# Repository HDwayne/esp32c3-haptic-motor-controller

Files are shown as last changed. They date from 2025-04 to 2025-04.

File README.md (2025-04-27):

# ESP32-C3 Haptic Motor Controller



The **ESP32-C3 Haptic Motor Controller** is a standalone board designed to drive multiple haptic motors, based on the ESP32-C3-MINI-1U module.  
It features a **DRV2605L** haptic driver for each motor. The board is powered by two parallel LiPo batteries.

> ⚠️ Warning: This project has not been tested and will not be tested. It is a concept prototype developed for a student project only. Use it at your own risk.

The PCB is a 4-layer board following the **JLC04161H-3313** stackup:
- **Outer layers**: signals.
- **Inner layers**: ground (GND) and 3.3 V power.

📏 Board dimensions: **80 mm x 35 mm**.

Here is a 3D model preview of the PCB layout:
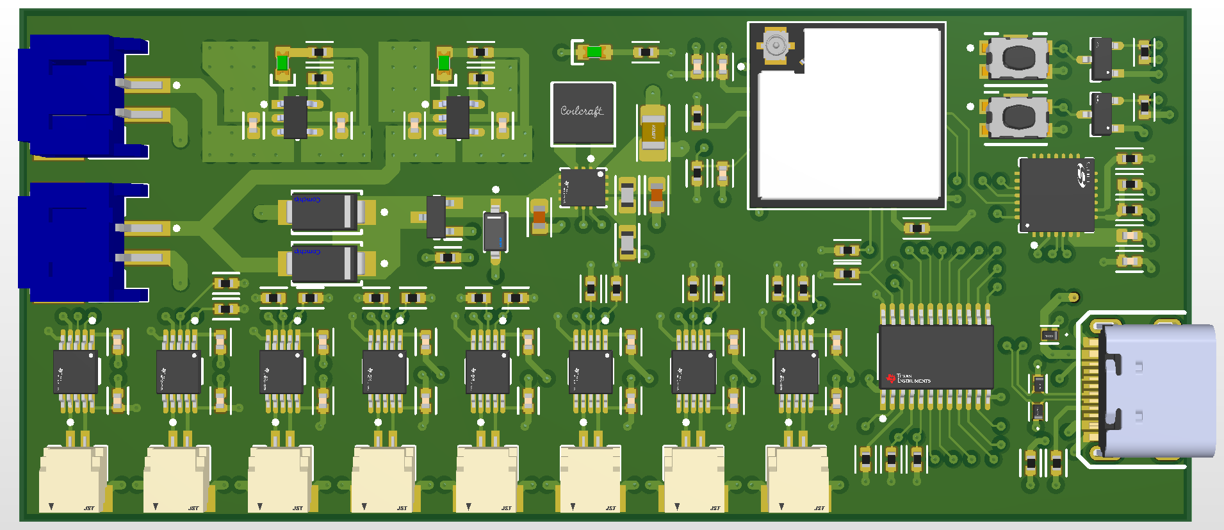
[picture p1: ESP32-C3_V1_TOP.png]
PCB 3D View BOTTOM

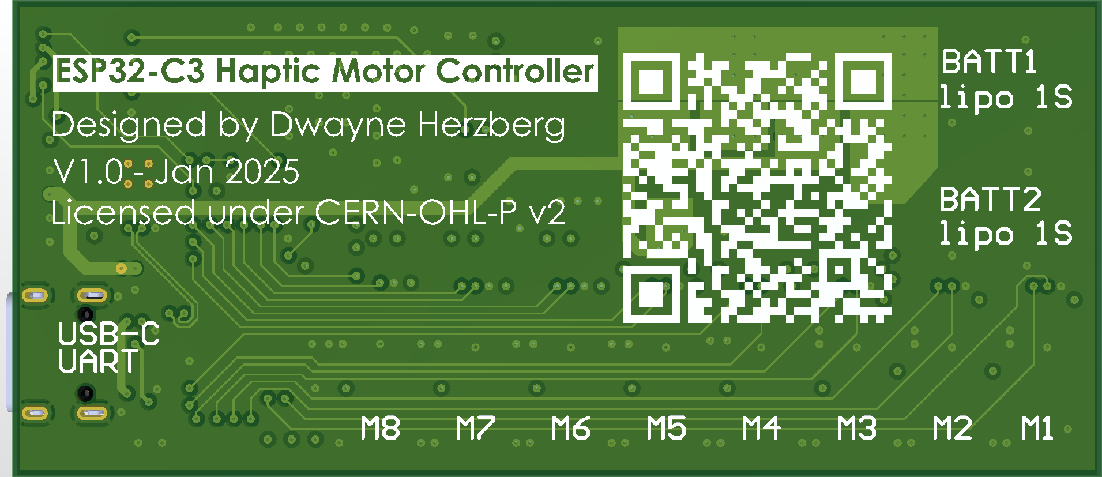
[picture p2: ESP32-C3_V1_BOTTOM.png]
PCB 3D View TOP


## Overview

- **ESP32-C3-MINI-1U** with Wi-Fi and Bluetooth LE
- **DRV2605L Haptic Drivers** (one per motor)
- **I²C Multiplexer TCA9548A**
- **Autonomous power** with two parallel LiPo batteries
- **TPS630250 Buck-Boost Converter** for stable 3.3 V
- **Simplified USB-C connector** for programming and charging
- **Independent battery chargers** for each battery
- **control buttons** (reset and boot)

## Project Contents

- **Altium Source Files** – Schematic and PCB Layout
- **Symbol & Footprint Libraries** – Custom libraries
- **Manufacturing Files** – Gerber files for PCB production
- **Assembly Files** – BOM and Pick & Place files

## License

This project is licensed under the [CERN Open Hardware Licence Version 2 – Permissive (CERN-OHL-P v2)](https://cern-ohl.web.cern.ch/).

See the `LICENSE.txt` file for full details.

---

**Dwayne Herzberg**  
Email: [dwayneherzberg@gmail.com](mailto:dwayneherzberg@gmail.com)

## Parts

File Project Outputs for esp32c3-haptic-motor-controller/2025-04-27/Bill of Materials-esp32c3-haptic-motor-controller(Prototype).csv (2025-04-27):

Comment | Description | Designator | Footprint | LibRef | Quantity | JLCPCB Part | Manufacturer | Manufacturer Part Number | Supplier | Supplier Part Number
1uF 35V | CAP CER 1UF 35V X5R 0402 | C1, C9, C10, C11, C12, C13, C14, C15, C16, C21, C22, C23, C24, C25, C26, C27, C28 | CAP_0402 | CL05A105KL5NRNC | 17 | C307413 | Samsung | CL05A105KL5NRNC | Digikey | 1276-6796-1-ND
0.1uF 50V | CAP CER 0.1UF 50V X7R 0402 | C2, C5 | CAP_0402 | CL05B104KB54PNC | 2 | C307331 | Samsung | CL05B104KB54PNC | Digikey | 1276-CL05B104KB54PNCCT-ND
10uF 10V | CAP CER 10UF 10V X5R 0402 | C3 | CAP_0402 | CL05A106MP8NUB8 | 1 | C307415 | Samsung | CL05A106MP8NUB8 | Digikey | 1276-6830-1-ND
4.7uF 16V | CAP CER 4.7UF 16V X5R 0402 | C4, C17, C18, C19, C20 | CAP_0402 | CL05A475MO5NUNC | 5 | C318563 | Samsung | CL05A475MO5NUNC | Digikey | 1276-6836-1-ND
10uF 10V | CAP CER 10UF 10V X5R 0603 | C6 | CAP_0603 | CL10A106KP8NNNC | 1 | C19702 | Samsung | CL10A106KP8NNNC | Digikey | 1276-1192-1-ND
10uF 6.3V | CAP CER 10UF 6.3V X5R 0603 | C7 | CAP_0603 | GRM188R60J106ME47D | 1 | C77041 | Murata | GRM188R60J106ME47D | Digikey | 490-3896-1-ND
47uF 6.3V | CAP CER 47UF 6.3V X5R 0805 | C8 | CAP_0805 | CL21A476MQYNNNE | 1 | C16780 | Samsung | CL21A476MQYNNNE | Digikey | 1276-1852-1-ND
AQ3045-01ETG | TVS DIODE 5.3VWM 12VC SOD882 | D2, D3, D4 | SP353001ETG | AQ3045-01ETG | 3 | C3710326 | Littelfuse | AQ3045-01ETG | Digikey | F9321CT-ND
GREEN | LED GREEN CLEAR 0603 SMD | D5, D8, D9 | LED_0603_GREEN | 150060GS75000 | 3 | C5252984 | Wurth Electronics | 150060GS75000 | Digikey | 732-4971-1-ND
40V 2A | DIODE SCHOTTKY 40V 2A DO214AC | D6, D7 | FP-DO-214AC-MFG | CDBA240LL-HF | 2 | C2886093 | Comchip | CDBA240LL-HF | Digikey | 641-1698-1-ND
40V 1A | DIODE SCHOTTKY 40V 1A SOD123 | D10 | FP-SOD123-IPC_B | 1N5819HW-7-F | 1 | C82544 | Diodes | 1N5819HW-7-F | Rs | 7082197P
TYPE-C-31-M-12 | USB Type C Connector Horizontal SMT | J1 | TYPE-C-31-M-12 | TYPE-C-31-M-12 | 1 | C165948 | Koren Hroparts | TYPE-C-31-M-12
S2B-PH-SM4-TB(LF)(SN) | Male Header, Pitch 2 mm, 1 x 2 Position, Height 5.5 mm, -25 to 85 degC, RoHS, Tape and Reel | J2, J7 | JST- S2B-PH-SM4-TB(LF)(SN)-2_V | CMP-1755-00001-1 | 2 | C295747
SM02B-SRSS-TB(LF)(SN) | CONN HEADER SMD R/A 2POS 1MM | J3, J4, J5, J6, J8, J9, J10, J11 | FP-SM02B-SRSS-TB_LF_SN-MFG | SM02B-SRSS-TB(LF)(SN) | 8 | C160402 | JST | SM02B-SRSS-TB(LF)(SN) | Future Electronics | 1161645
1uH | FIXED IND 1UH 9.6A 14.6MOHM SM | L1 | FP-XAL4020-102MEC-MFG | XAL4020-102MEC | 1 | C4555951 | Coilcraft | XAL4020-102MEC | Mouser | 994-XAL4020-102MEC
SS8050-G | TRANS NPN 25V 1.5A SOT-23-3 | Q1, Q2 | FP-SS8050-G-IPC_B | SS8050-G | 2 | C3199946 | Comchip | SS8050-G | Digikey | 641-1790-1-ND
DMP2045U-7 | MOSFET P-CH 20V 4.3A SOT23 | Q3 | SOT96P240X115-3N | DMP2045U-7 | 1 | C459541 | Diodes | DMP2045U-7 | Rs | 1827098P
10K | RES SMD 10K OHM 1% 1/16W 0402 | R1, R7, R8, R9, R10, R11, R12, R13, R14, R15, R16, R17, R18, R19, R20, R21, R22, R23, R24, R25, R26, R27, R28, R29 | RES_0402 | AC0402FR-0710KL | 24 | C144807 | Yageo | AC0402FR-0710KL | Digikey | YAG3436CT-ND
1K | RES 1K OHM 5% 1/16W 0402 | R2, R30, R33, R35 | RES_0402 | RC0402JR-071KL | 4 | C105637 | Yageo | RC0402JR-071KL | Digikey | 311-1.0KJRCT-ND
22K1 | RES 22.1K OHM 1% 1/16W 0402 | R3 | RES_0402 | RC0402FR-0722K1L | 1 | C163478 | Yageo | RC0402FR-0722K1L | Rs | 1987704
47K5 | RES 47.5K OHM 1% 1/16W 0402 | R4 | RES_0402 | RC0402FR-0747K5L | 1 | C137974 | Yageo | RC0402FR-0747K5L | Rs | 1987797
5K1 | RES SMD 5.1K OHM 1% 1/16W 0402 | R5, R6 | RES_0402 | AC0402FR-075K1L | 2 | C144745 | Yageo | AC0402FR-075K1L | Digikey | YAG3503CT-ND
562K | RES SMD 562K OHM 1% 1/10W 0603 | R31 | RES_0603 | AC0603FR-07562KL | 1 | C227963 | Yageo | AC0603FR-07562KL | Digikey | 13-AC0603FR-07562KLCT-ND
180K | RES 180K OHM 1% 1/10W 0603 | R32 | RES_0603 | RC0603FR-07180KL | 1 | C123419 | Yageo | RC0603FR-07180KL | Digikey | 311-180KHRCT-ND
2K7 | RES 2.7K OHM 1% 1/16W 0402 | R34, R36 | RES_0402 | RC0402FR-072K7L | 2 | C138017 | Yageo | RC0402FR-072K7L | Digikey | 311-2.70KLRCT-ND
100K | RES 100K OHM 1% 1/16W 0402 | R37 | RES_0402 | RC0402FR-07100KL | 1 | C60491 | Yageo | RC0402FR-07100KL | Rs | 1987640
KMR221GLFS | SWITCH TACTILE SPST-NO 0.05A 32V | SW1, SW2 | FP-KMR221GLFS-MFG | KMR221GLFS | 2 | C72443 | ITT C&K | KMR221GLFS | Digikey | 401-1427-1-ND
CP2102N-A02-GQFN28 | IC USB TO UART BRIDGE QFN28 | U1 | FP-CP2102N-A02-GQFN28-IPC_B | CP2102N-A02-GQFN28 | 1 | C1550553 | Silicon Labs | CP2102N-A02-GQFN28 | Rs | 1871341P
ESP32-C3-MINI-1U-N4 | RF TXRX MOD BT WIFIU.FL SMD | U2 | ESP32-C3-MINI-1U_EXP | ESP32-C3-MINI-1U-N4 | 1 | C2911374 | Espressif Systems | ESP32-C3-MINI-1U-N4 | Digikey | 1965-ESP32-C3-MINI-1U-N4CT-ND
TCA9548APWR | IC BUS SWITCH 1 X 8:1 24TSSOP | U3 | FP-PW0024A-IPC_B | TCA9548APWR | 1 | C130026 | Texas Instruments | TCA9548APWR | Mouser | 595-TCA9548APWR
TPS630250RNCT | IC REG BCK BST ADJ 2A/4A 14VQFN | U4 | FP-RNC0014A-MFG | TPS630250RNCT | 1 | C2070882 | Texas Instruments | TPS630250RNCT | Digikey | 296-42036-1-ND
DRV2605LDGSR | IC MOTOR DRIVER 2V-5.5V 10VSSOP | U5, U6, U7, U8, U11, U12, U13, U14 | FP-DGS0010A-IPC_B | DRV2605LDGSR | 8 | C527464 | Texas Instruments | DRV2605LDGSR | Mouser | 595-DRV2605LDGSR
MCP73831T-2ACI/OT | IC BATT CNTL LI-ION 1CEL SOT23-5 | U9, U10 | FP-C04-091-OT-IPC_B | MCP73831T-2ACI/OT | 2 | C424093 | Microchip | MCP73831T-2ACI/OT | Digikey | MCP73831T-2ACI/OTCT-ND

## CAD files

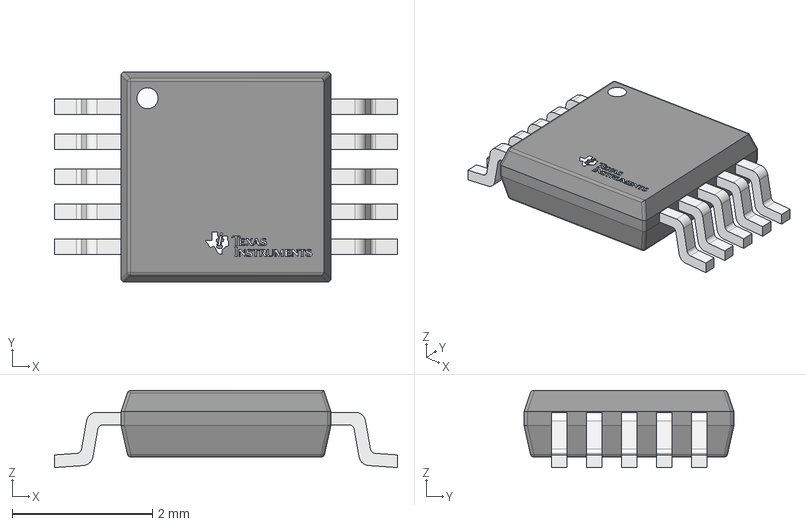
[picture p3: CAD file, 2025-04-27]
CAD/IC_Texas_Instruments_TS5A23159DGSR_eec.STEP
4.90 x 3.00 x 1.10 mm
IC_BODY
IC_LEG x 5
circle
IC_LEG_MIR7 x 5
Texas Instruments

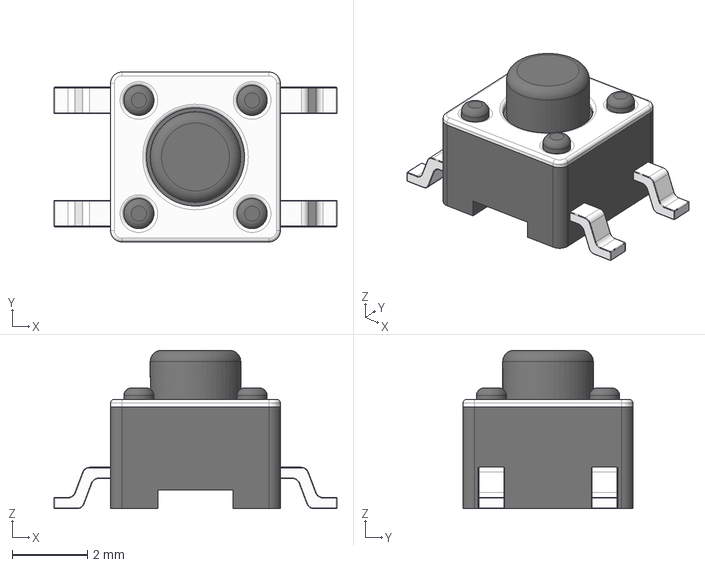
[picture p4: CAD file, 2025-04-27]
CAD/Tact Switch 4.5mm SMT.step
7.50 x 4.50 x 4.20 mm

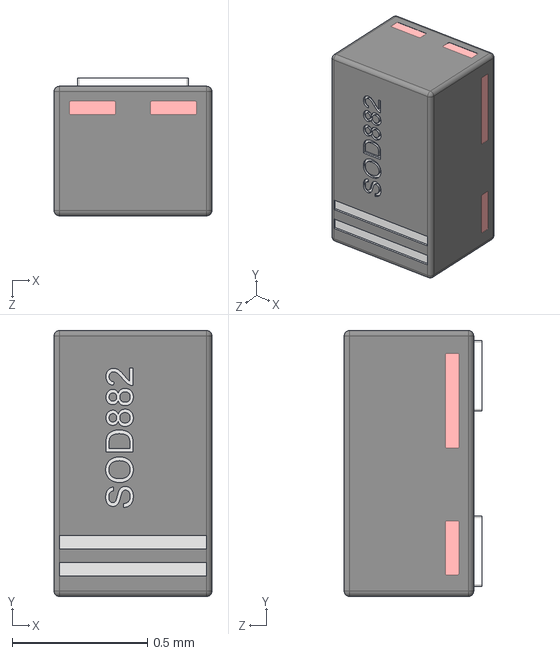
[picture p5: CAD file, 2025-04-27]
CAD/User Library-SOD882-1.step
0.585 x 0.985 x 0.51 mm

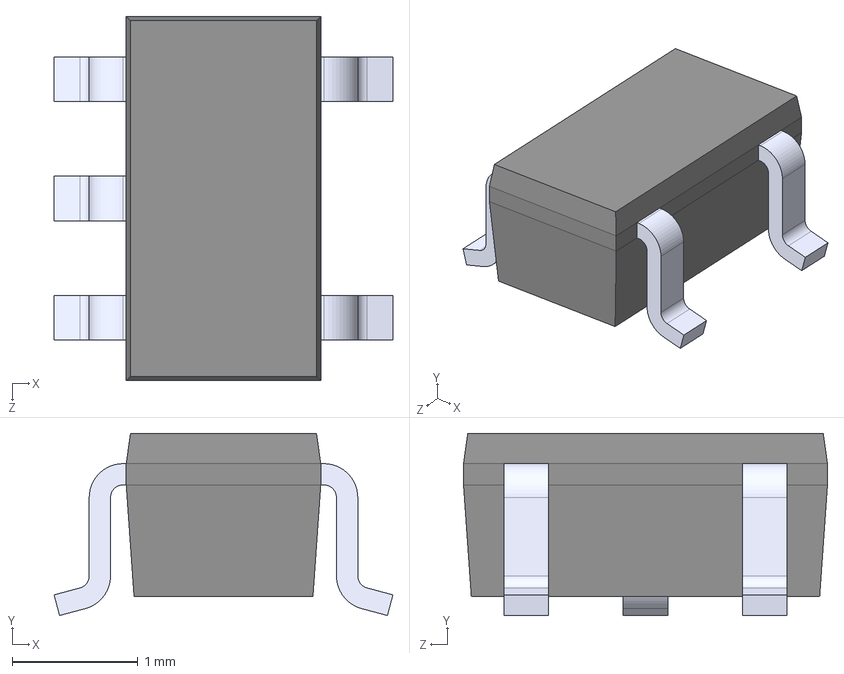
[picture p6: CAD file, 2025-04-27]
CAD/MCP73831T-2ACI_OT.step
2.70 x 1.45 x 2.90 mm

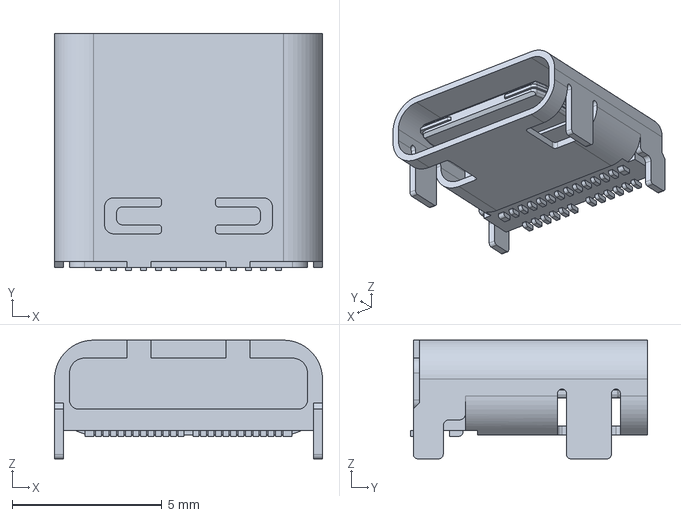
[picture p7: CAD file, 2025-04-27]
CAD/105450-0101.stp
8.94 x 7.90 x 3.96 mm

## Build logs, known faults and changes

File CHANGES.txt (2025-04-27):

CHANGES for Triboard-TC3X7-Extension
=====================================

Initial release

- 2024-04-27:
  - Project published under CERN-OHL-P v2 license.
  - Initial clean commit with latest hardware design files V1.0.

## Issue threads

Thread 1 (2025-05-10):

Project Contents？

typetrade, 2025-05-10:
Altium Source Files – Schematic and PCB Layout
Symbol & Footprint Libraries – Custom libraries used in the design
Manufacturing Files – Gerber files for PCB production
Assembly Files – BOM (Bill of Materials) and Pick & Place files for assembly

How to produce a test board？

HDwayne, 2025-05-22:
Hi, sorry for the delay.

Please zip all the files starting with `ESP32-C3_VA.*` located under the folder: `esp32c3-haptic-motor-controller\2025-04-27\Project Outputs.`

Then drop this ZIP file into the Gerber ZIP drop zone on JLCPCB.

It should automatically analyze the PCB. Check that the board size is 80×35 mm and it's a 4-layer board.
I’ll let you tune the settings as you wish.
Make sure to enable impedance control using the JLC04161H-3313 profile.

For PCB Assembly :
- Upload the CPL file: "Pick Place for ESP32-C3_V1(Prototype)"
- Upload the BOM file: "Bill of Materials-esp32c3-haptic-motor-controller(Prototype)"

**Note:** Some components might now be out of stock. Please check and replace any unavailable parts as needed.

Lastly, verify component placement and orientation carefully.

You should now be ready to order the PCB. Estimated cost is around $200 for 5 assembled boards (PCBA).

⚠️ WARNING: This project is a proof of concept created during a university project. It has not been verified or tested. Please double-check the PCB and all files before submitting your order.

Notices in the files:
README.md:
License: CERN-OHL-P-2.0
